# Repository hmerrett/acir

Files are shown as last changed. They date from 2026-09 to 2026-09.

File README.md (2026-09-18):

# acir

Control a CostWay mini-split air conditioner over IR from a Raspberry Pi Pico W,
exposed to Home Assistant as a `climate` entity via MQTT.

The unit speaks **TCL112**. That was established by capturing the original
remote, not by guessing — see [Protocol](#protocol).

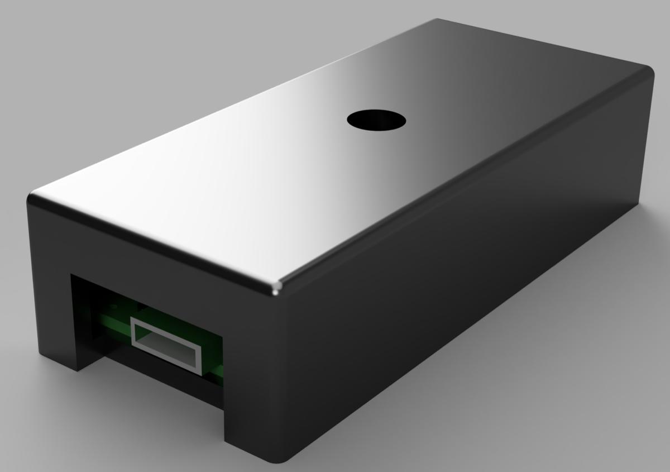
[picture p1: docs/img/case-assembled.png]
Assembled case


## Status

Working and in use — confirmed controlling the AC end to end, from the Home
Assistant UI through MQTT to the unit. Tested with:

- Raspberry Pi Pico W (RP2040), MicroPython 1.29.0
- CostWay portable AC with a TCL-family remote (`23 CB 26` prefix)
- Home Assistant 2026.8.3, MQTT discovery, Mosquitto
- Broadlink RM Pro — capture only, not needed at runtime

## Hardware

A Pico GPIO sources ~12 mA. An IR LED wants 100 mA+ for useful range, so the
GPIO switches a transistor.

```
 VBUS (5V) ──[33Ω ½W]──▶|── IR LED ──┐
                                     │ collector
                                    ┌┴┐
 GP15 ──[330Ω]──── base ────────────┤ │ 2N2222A
                                    └┴┘
                                     │ emitter
                                    GND
```

| From | Via | To |
|---|---|---|
| VBUS (pin 40) | 33 Ω ½W | LED anode (long leg) |
| LED cathode | — | transistor collector |
| GP15 (pin 20) | 330 Ω | transistor base |
| emitter | — | GND (pin 38) |

Add **100 µF + 100 nF across the 5 V rail next to the LED**. Without it, 100 mA
pulses at 38 kHz ripple the rail enough to brown out the wifi chip, which
presents as random dropouts.

Optional, for capture: a TSOP38238 on GP16, with 100 Ω in its supply line.

Gotchas:

- VBUS only has 5 V when powered over USB. From VSYS, use 3V3 with 15 Ω.
- The IR receiver's middle pin is GND; the outer two vary by manufacturer.
- Boards sold as "RP2040 Pico W" with USB-C are clones using an ESP8285 on
  UART0, not a CYW43. MicroPython's `network.WLAN` cannot drive them.
- Don't use GP23/24/25/29 — wifi and power circuitry.

## Case

Two-part printed enclosure. The hole in the lid is for the IR LED; the cutout
at the end clears the USB connector.

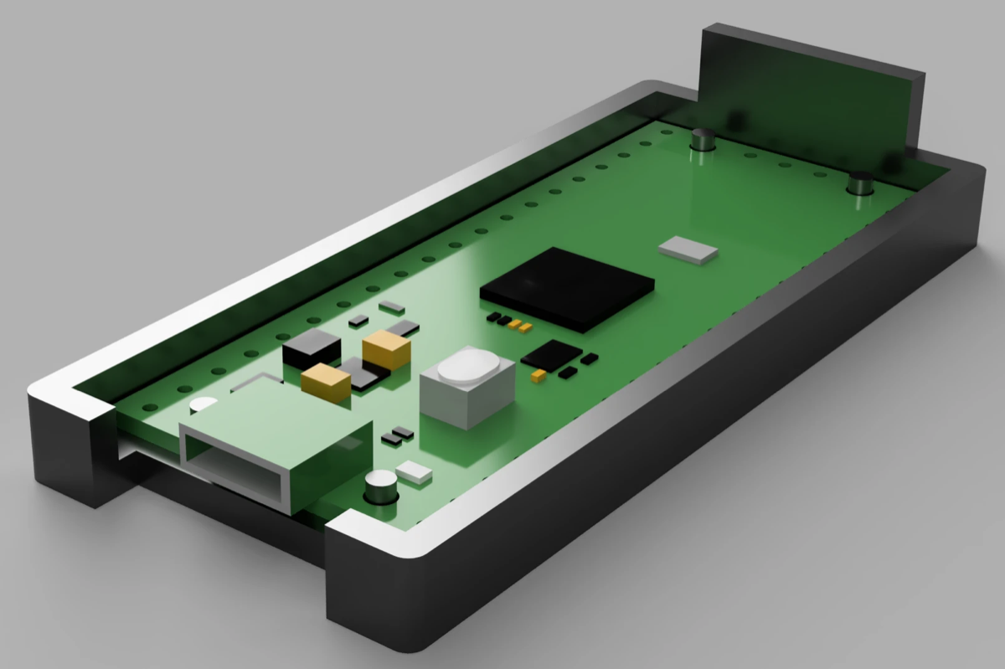
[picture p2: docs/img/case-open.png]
Case interior


STL: [`hardware/pico-case.stl`](hardware/pico-case.stl). Printed in PETG, no
supports needed.

## Install

```
mpremote connect auto mip install umqtt.simple
cp src/secrets.example.py src/secrets.py   # then edit it
mpremote connect auto fs cp src/*.py :
mpremote connect auto reset
```

`main.py` runs at boot. ~10 s from reset to MQTT online. USB supplies power
only; all traffic is wifi, so a phone charger is fine.

**Any `mpremote` command stops the bridge** — it sends Ctrl-C to get a REPL and
doesn't restart `main.py`. Finish with `mpremote connect auto reset`.

## Use

From Home Assistant, the entity appears by itself via MQTT discovery. Directly:

```python
import ac
ac.on(temp=20, fan='high')
ac.set(mode='dry')
ac.off()
```

Topics are listed in [docs/INTEGRATION.md](docs/INTEGRATION.md).

## Protocol

TCL112: 112-bit frames, bytes LSB-first, prefix `23 CB 26`, checksum in byte 13.
Every press sends two blocks — a constant preamble (`MsgType 0x02`) then the
state (`0x01`) — separated by 69.9 ms.

| Field | Location |
|---|---|
| Power | byte 5 bit 2 |
| Econo | byte 5 bit 7 |
| Mode | byte 6 bits 0-3 — heat 1, dry 2, cool 3, fan 7, auto 8 |
| Turbo | byte 6 bit 6 |
| I Feel | byte 6 bit 7 |
| Temp | byte 7 bits 0-3, encoded as `31 - °C` |
| Fan | byte 8 bits 0-2 — auto 0, min 1, low 2, med 3, high 5 (4 unused) |
| SwingV | byte 8 bits 3-5 |
| Checksum | byte 13, `sum(bytes[0:13]) & 0xFF`, +0x0F when byte 3 is 0x02 |

Mapped by capturing 18 scenarios from the real remote and diffing them.
**Turbo is byte 6 bit 6, not bit 5** as IRremoteESP8266 documents — this unit
disagrees with the reference implementation.

Raw captures are in `captures/remote.json`.

## Tests

```
python3 tests/run.py
```

Runs the firmware under CPython with `machine` and `rp2` stubbed. Covers carrier
arithmetic, µs-to-carrier-period rounding, the capture state machine, and the
Coolix/Gree/Midea/TCL112 encoders. 14 frames captured from the real remote are
regression fixtures — if the encoder stops reproducing them, the tests fail.

## Layout

```
src/            firmware for the Pico
tools/          host-side capture and analysis (needs a Broadlink RM)
tests/          host-side tests, no hardware
docs/           Home Assistant and HomeBridge setup
hardware/       printable case
captures/       IR frames captured from the original remote
```

## Notes

The 38 kHz carrier is generated by a PIO state machine; bit-banging it from
MicroPython has worse jitter than the pulse widths. Intervals are counted in
whole carrier periods (26.3 µs) so the state machine never divides — 1.25%
error on a 560 µs pulse, against the ±20% a receiver tolerates.

IR is one-way. Published state is what was last *sent*. Using the physical
remote desyncs it until the next command.

## Licence

MIT

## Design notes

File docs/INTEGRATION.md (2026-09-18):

# Home Assistant and HomeBridge

The Pico publishes MQTT. Home Assistant picks it up by discovery; HomeBridge
reads the same topics via `homebridge-mqttthing`. Neither depends on the other.

```
  Pico W ──IR──> AC
     │
     └──MQTT──> broker ──┬──> Home Assistant   climate entity
                         └──> HomeBridge       heaterCooler
```

## Broker

Any MQTT broker. On Home Assistant OS: Settings → Add-ons → Mosquitto broker →
Install → Start, then accept the MQTT integration when it offers itself.

## Pico

Put the broker details in `src/secrets.py`:

```python
MQTT_HOST = "192.168.1.10"
MQTT_PORT = 1883
MQTT_USER = None
MQTT_PASSWORD = None
MQTT_DISCOVERY_PREFIX = "homeassistant"
```

```
mpremote connect auto fs cp src/*.py :
mpremote connect auto reset
```

The climate entity appears by itself. Discovery is published retained, so HA
recreates it after a restart without the Pico being awake.

## Topics

| Topic | Direction | Payload |
|---|---|---|
| `acir/costway/availability` | Pico → | `online` / `offline` (last will) |
| `acir/costway/state` | Pico → | JSON: mode, temperature, fan_mode, swing_mode, preset_mode |
| `acir/costway/set/mode` | → Pico | `off` `cool` `heat` `dry` `fan_only` `auto` |
| `acir/costway/set/temperature` | → Pico | 16–31 |
| `acir/costway/set/fan_mode` | → Pico | `auto` `min` `low` `med` `high` |
| `acir/costway/set/swing_mode` | → Pico | `off` `vertical` |
| `acir/costway/set/preset_mode` | → Pico | `none` `eco` `boost` |

```
mosquitto_sub -h <broker> -t 'acir/#' -v
```

## HomeBridge

```
npm install -g homebridge-mqttthing
```

Add `homebridge-mqttthing.json` to `config.json` under `accessories`, setting
`url` to your broker.

HomeKit's `HeaterCooler` requires a current temperature and there is no sensor,
so the config reports the target temperature as current. If that matters, point
`getCurrentTemperature` at a real sensor's topic instead.

New accessories do not reach an already-paired bridge until it reloads.

## One-way control

The AC does not report back. State published is what was last sent; the
physical remote will desync it until the next command. Fixable with an IR
receiver watching for the remote's frames — `ir_rx.py` and `capture.py` already
do the decoding.

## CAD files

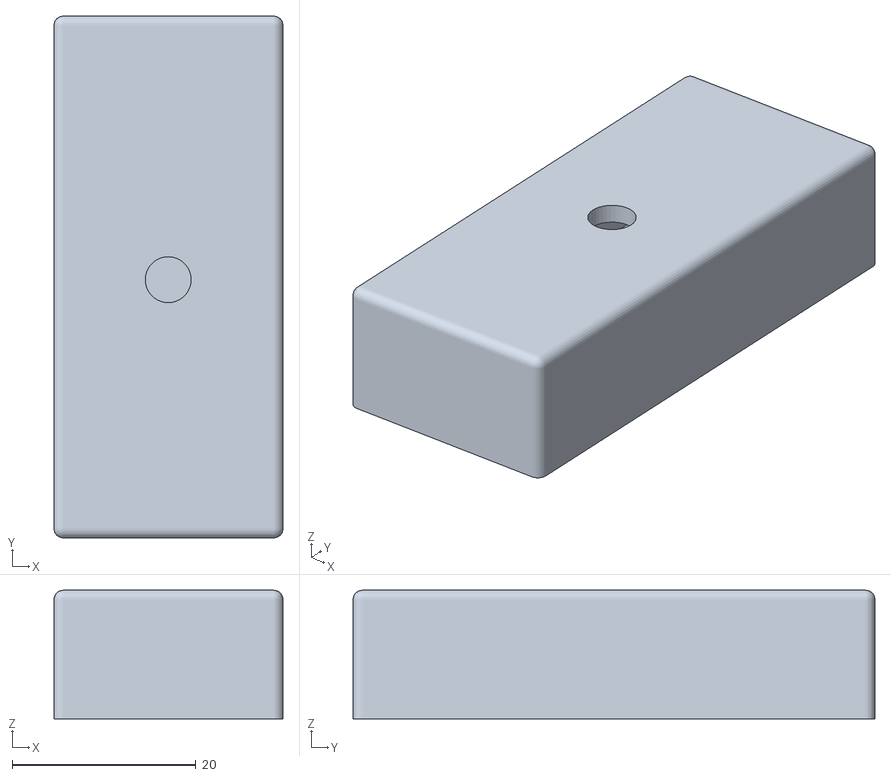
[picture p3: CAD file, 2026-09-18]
hardware/pico-case.stl
24.9 x 56.8 x 14.0

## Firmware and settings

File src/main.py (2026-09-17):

"""Runs on boot. Connects to wifi and serves MQTT until told otherwise."""

import time


def start():
    import mqtt_bridge
    mqtt_bridge.run()


if __name__ == "__main__":
    # A short pause makes it possible to interrupt with Ctrl-C and get a REPL
    # before the bridge takes over the board.
    print("acir starting in 3s -- Ctrl-C for a REPL")
    try:
        time.sleep(3)
    except KeyboardInterrupt:
        raise SystemExit("cancelled")
    start()

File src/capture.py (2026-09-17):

"""Interactive capture tool: learn the air conditioner's remote.

Typical session over the REPL:

    >>> import capture
    >>> capture.run()

Point the original remote at the receiver from ~30 cm, set it to the state you
want, and press a button. Each frame is summarised and appended to captures.json
on the Pico's flash.

Capture the same button two or three times. Air conditioner remotes are stateful
-- every frame carries the whole machine configuration plus a checksum -- so two
presses of "temperature up" produce different frames. Two presses of the same
*resulting state* should produce identical ones, and that is the check that tells
you the capture is sound.
"""

import json
import time

import config
import ir_rx
from ir_rx import IRReceiver

# Two intervals this close are the same symbol as far as the protocol cares.
MATCH_TOLERANCE = 0.25


def load(path=None):
    path = path or config.CAPTURE_FILE
    try:
        with open(path) as f:
            return json.load(f)
    except (OSError, ValueError):
        return {}


def save(label, frame, path=None):
    path = path or config.CAPTURE_FILE
    data = load(path)
    data.setdefault(label, []).append(frame)
    with open(path, "w") as f:
        json.dump(data, f)
    return len(data[label])


def frames_match(a, b, tolerance=MATCH_TOLERANCE):
    if len(a) != len(b):
        return False
    for x, y in zip(a, b):
        if abs(x - y) > tolerance * max(x, y):
            return False
    return True


def compare(a, b, tolerance=MATCH_TOLERANCE):
    """Show where two frames diverge.

    The useful move once you have several captures: take "cool 20" and
    "cool 21" and see which intervals changed. Those are the temperature bits,
    and the ones that always change alongside them are the checksum.
    """
    if len(a) != len(b):
        print("different lengths: {} vs {}".format(len(a), len(b)))
        return

    diffs = 0
    for i, (x, y) in enumerate(zip(a, b)):
        if abs(x - y) > tolerance * max(x, y):
            kind = "mark " if i % 2 == 0 else "space"
            print("  [{:>3}] {} {:>6} -> {:>6}".format(i, kind, x, y))
            diffs += 1

    if diffs == 0:
        print("  identical")
    else:
        print("  {} of {} intervals differ".format(diffs, len(a)))


def run(path=None):
    rx = IRReceiver(config.IR_RX_PIN)
    print("Ready. Point the remote at the receiver from about 30 cm.")
    print("Label each capture with the resulting state, e.g. 'cool_20_fan_high'.")
    print("Blank label to quit.\n")

    try:
        while True:
            label = input("label> ").strip()
            if not label:
                break

            rx.reset()                     # discard anything already buffered
            print("  waiting for a press...")
            frame = rx.wait(timeout_ms=30000)
            if frame is None:
                print("  timed out, nothing received\n")
                continue

            print()
            ir_rx.summarise(frame)

            previous = load(path).get(label, [])
            n = save(label, frame, path)
            print("\n  saved as '{}' capture #{}".format(label, n))

            if previous:
                if frames_match(previous[-1], frame):
                    print("  matches the previous capture of this label -- good")
                else:
                    print("  DIFFERS from the previous capture of this label:")
                    compare(previous[-1], frame)
            print()
    finally:
        rx.deinit()

    data = load(path)
    print("\n{} label(s) captured: {}".format(len(data), ", ".join(data.keys())))


def dump(path=None):
    """Print every stored capture as Python lists, ready to paste elsewhere."""
    for label, frames in load(path).items():
        for i, frame in enumerate(frames):
            print("# {} #{} -- {} intervals".format(label, i + 1, len(frame)))
            print("{} = {}\n".format(label.upper(), frame))


if __name__ == "__main__":
    run()

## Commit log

2026-09-17 CostWay AC control over IR from a Pico W
    Drives the AC with a 38kHz carrier generated by PIO, and exposes it to
    Home Assistant as a climate entity over MQTT.
    The unit turned out to speak TCL112. Worked that out by capturing the
    original remote with a Broadlink RM, calibrating its tick against the
    Pico's own transmitter, then diffing 18 captured scenarios to map the
    fields. Encoder reproduces all 14 reference frames byte for byte.
    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
2026-09-18 Add printed case, renders, and aiming helper
    Confirmed working against the AC end to end.
    ac.blast() toggles power repeatedly so the LED can be aimed at the
    unit's receiver window without going via Home Assistant each time.
    [pico-case.stl]
